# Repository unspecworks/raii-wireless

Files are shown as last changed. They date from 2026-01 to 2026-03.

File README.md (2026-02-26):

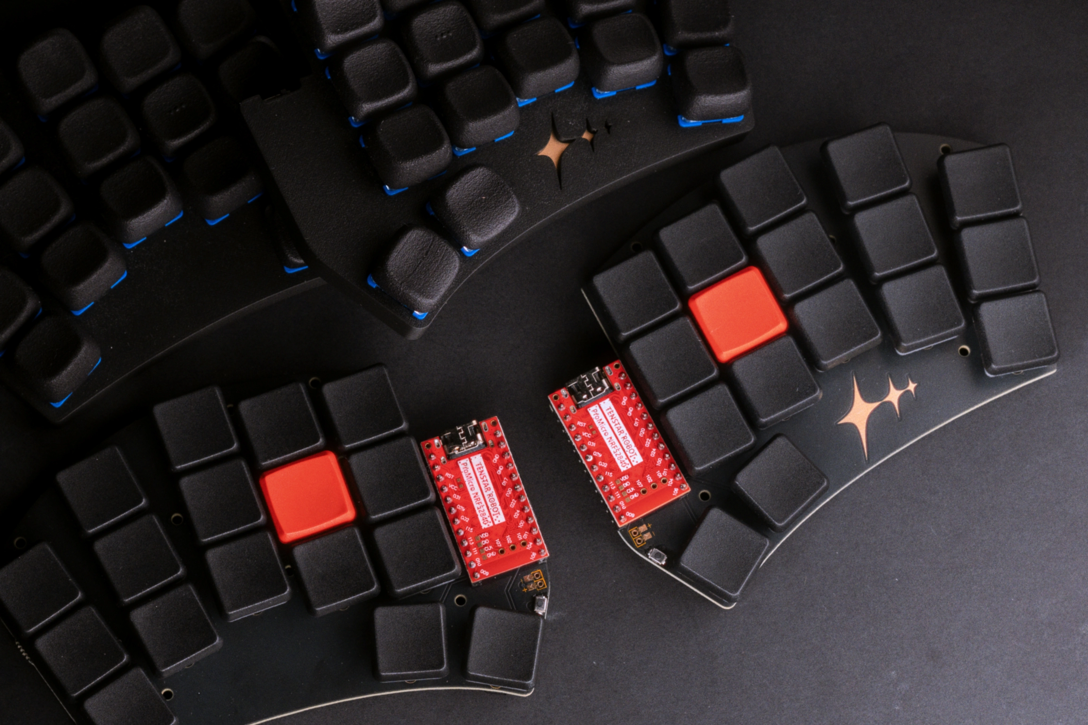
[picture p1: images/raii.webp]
RAII


# RAII Wireless

RAII-Wireless is a customized variant of [Sweep Bling LP](https://github.com/davidphilipbarr/Sweep), featuring splayed columns and various PCB and footprint updates.

## Modifications

* Applied splay to the ring and pinky columns
* Added support for Kailh Choc V2
* Compatible with Nice!Nano v2 or Pro Micro MCUs

## Project Structure

*   **[PCB](./pcb)**: KiCad design files.
*   **[Cases](./cases)**: 3D printable case files (STEP).
*   **[Images](./images)**: Gallery of the RAII Wireless keyboard.
*   **[Build Guide](./BUILD_GUIDES.md)**: Detailed assembly instructions and Bill of Materials.

### Firmware
* **ZMK Firmware**: You can use the Cradio firmware, which is the same as the Sweep's.

### Related
* **Wired Version**: [raii](https://github.com/unspecworks/raii) (Wired version with integrated RP2040)

## Sponsorship

This project is sponsored by [PCBWay](https://www.pcbway.com/).

> Note: PCBWay is a manufacturer of PCBs, and they sponsored this project by providing free PCBs. I really appreciate their support.

## License

[SOLDERPAD HARDWARE LICENSE VERSION 2.1](./LICENSE)

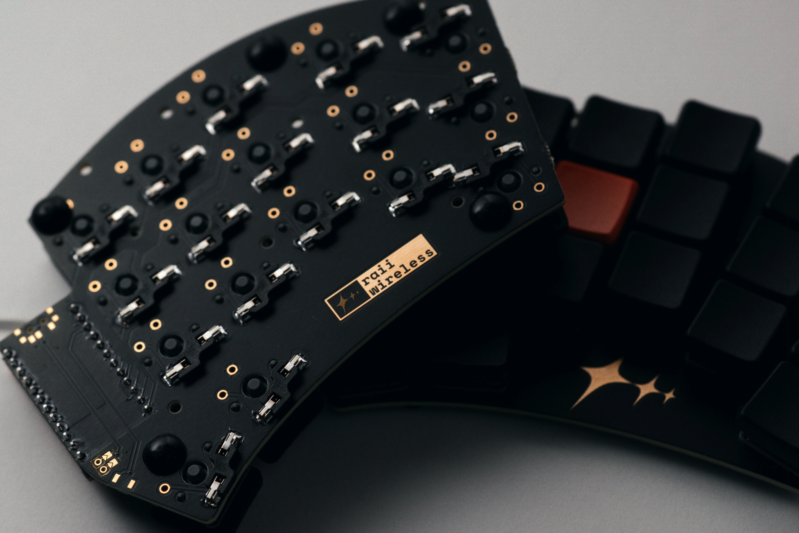
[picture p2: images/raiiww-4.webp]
RAII


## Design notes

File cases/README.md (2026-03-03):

# RAII Wireless Cases

This directory contains the 3D design files (STEP format) for the RAII Wireless keyboard cases.

## Overview

The RAII Wireless case is a two-part (Top and Bottom) case designed to house the PCB, battery, and switches securely.

## Case Files

Files are provided in STEP format, which is compatible with most 3D CAD software and slicers.

### Left Half
- `RAII_W_L_TOP.step`: Top plate/shell for the left side.
- `RAII_W_L_BOT.step`: Bottom shell for the left side.

### Right Half
- `RAII_W_R_TOP.step`: Top plate/shell for the right side.
- `RAII_W_R_TOP_LOGO.step`: Top plate/shell for the right side with logo on the top.
- `RAII_W_R_BOT.step`: Bottom shell for the right side.

## Hardware Requirements

To assemble the case, you will need:

- **Screws**: M2x6mm screws (8 total, 4 per side).
- **Feet**: Rubber feet or anti-slip pads for the bottom case.

## Design Features

- **Reset Mechanism**: The bottom case includes a built-in leaf spring mechanism to actuate the reset switch without needing to open the case.
- **Battery Compartment**: Designed to accommodate a 3.7V LiPo battery (recommended size: 351636 for case builds).
- **Slim Fit**: Optimized for a low-profile aesthetic that protects the MCU and battery while keeping the switches and keycaps exposed.

## Printing Recommendations

- **Material**: PLA, PETG
- **Orientation**: Print with the flat faces on the bed.
- **Supports**: May be required depending on your printer's bridging capabilities, especially for the screw holes and internal cavities.

> [!WARNING]
> This case is designed for FDM printing. Other methods, such as resin printing, may not be suitable for this design.

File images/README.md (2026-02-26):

# Gallery

This directory contains images of the RAII Wireless keyboard.

RAII
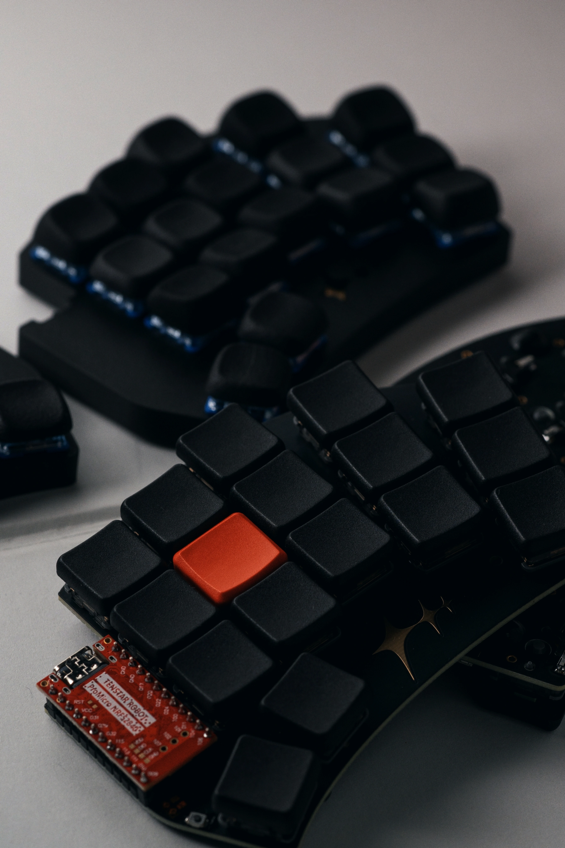
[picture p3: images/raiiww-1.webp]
RAII Wireless 1

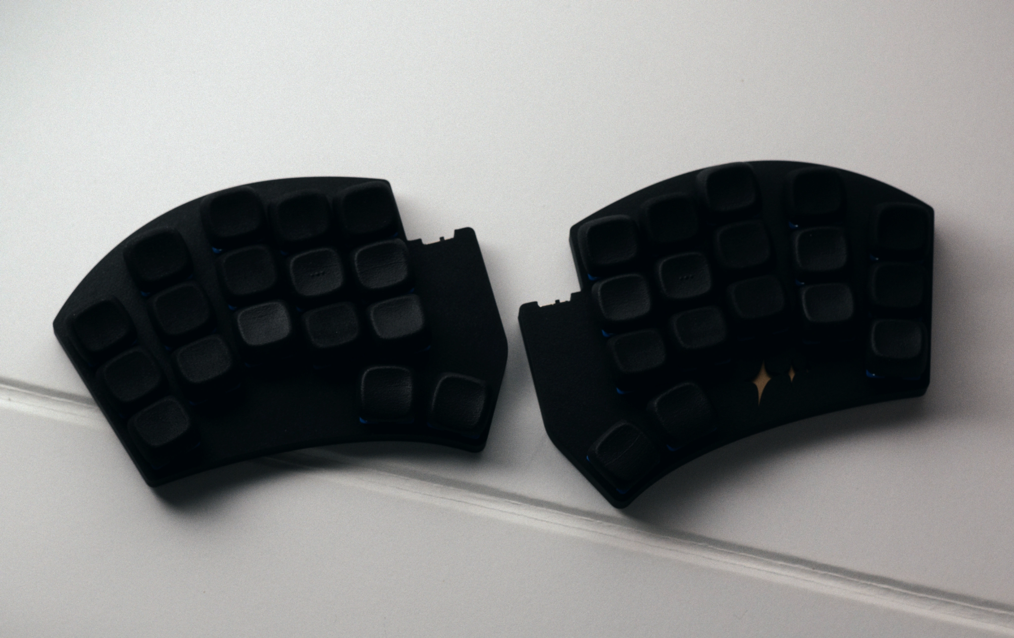
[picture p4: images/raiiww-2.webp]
RAII Wireless 2

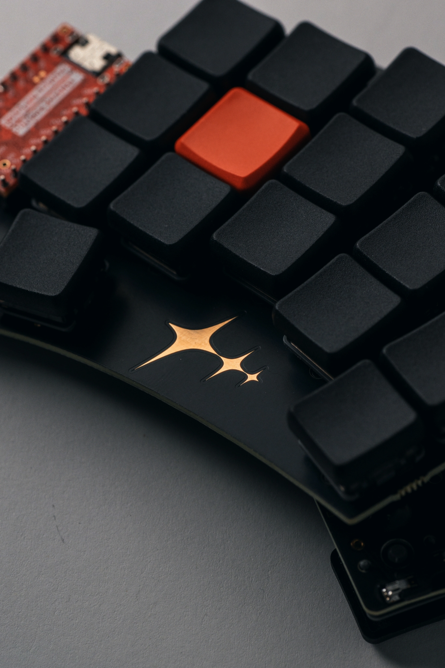
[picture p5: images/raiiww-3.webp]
RAII Wireless 3

RAII Wireless 4
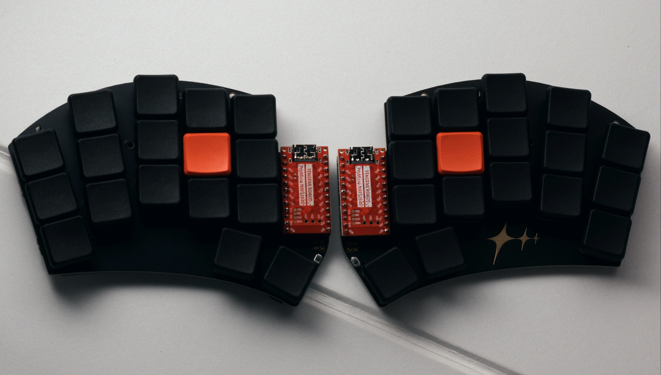
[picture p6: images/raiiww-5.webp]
RAII Wireless 5

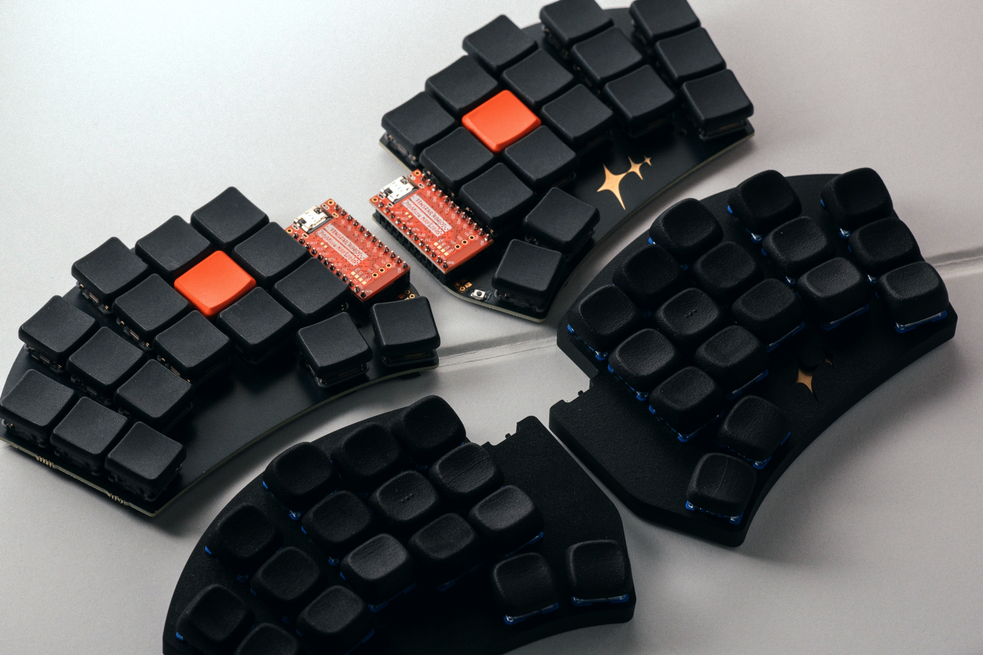
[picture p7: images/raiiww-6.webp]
RAII Wireless 6


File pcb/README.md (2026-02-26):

# RAII Wireless PCB

This directory contains the PCB design files for the RAII Wireless keyboard.

## Files

- `raii-wireless-rev1.kicad_pcb`: The main PCB design file (KiCad).

## Ordering Guide

To order these PCBs, you can upload the KiCad file or exported Gerbers to [PCBWay](https://www.pcbway.com/).

### Recommended Settings:
- **Material**: FR-4
- **Layer**: 2
- **Thickness**: 1.6mm
- **Surface Finish**: **ENIG** (Highly recommended) or HASL (Lead-free recommended)
- **Solder Mask**: **Matte Black Solder Mask**
- **Different designs in panel**: 2 (Left and Right halves)

> *Note: In my experience, PCBWay consistently delivers boards that meet exact technical specifications. Their range of customization options is significantly broader than those of many other services. For projects where the PCB is exposed, their **Matte Black Solder Mask** provides a particularly refined aesthetic. Considering the premium options available, the pricing is very reasonable and the production speed is impressive. I personally recommend the combination of **ENIG** and **Matte Black Solder Mask** for this build.*

## Building Tips

- **Battery Jumper**: Ensure you bridge the appropriate battery jumpers on the PCB before connecting your battery.
- **MCU Orientation**: Refer to the [Build Guide](../BUILD_GUIDES.md) for specific MCU orientation depending on whether you are using a case.

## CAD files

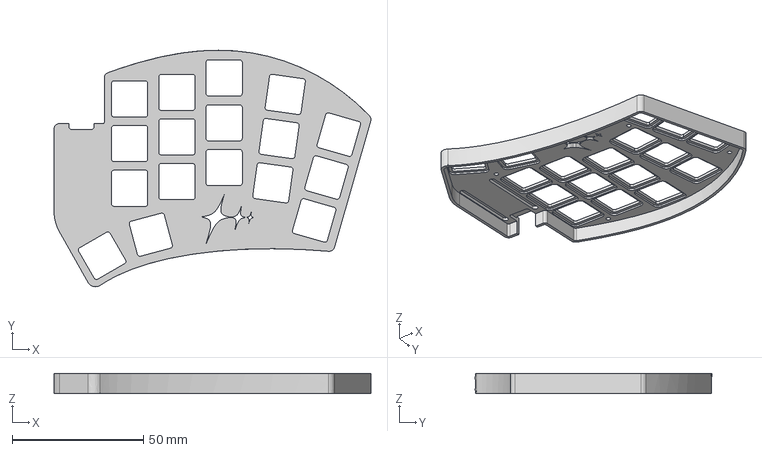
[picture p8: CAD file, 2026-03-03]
cases/RAII_W_R_TOP_LOGO.step
120.7 x 90.1 x 7.80 mm

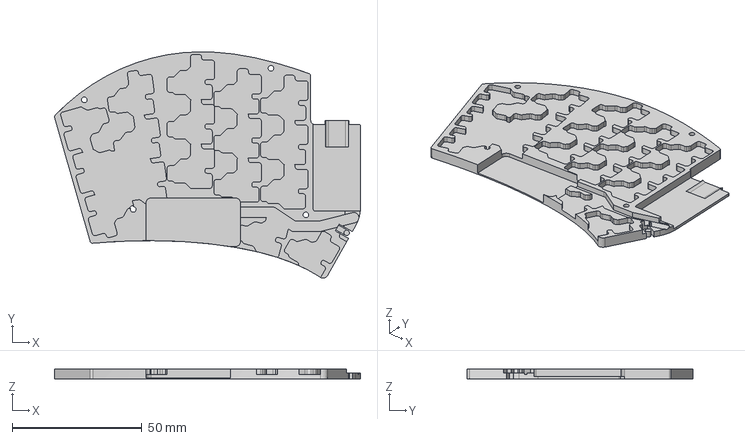
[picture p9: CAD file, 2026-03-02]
cases/RAII_W_L_BOT.step
117.8 x 87.1 x 4.00 mm

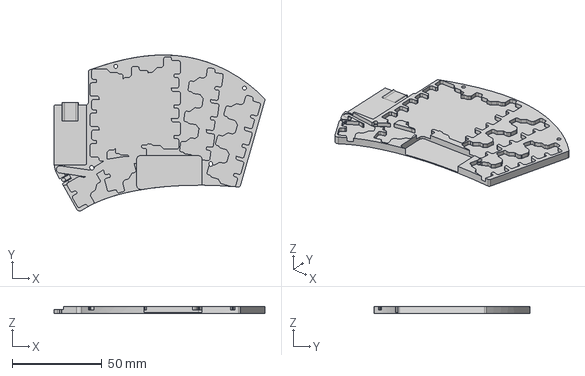
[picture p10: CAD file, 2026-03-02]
cases/RAII_W_R_BOT.step
117.8 x 87.1 x 4.00 mm

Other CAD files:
cases/RAII_W_L_TOP.step
cases/RAII_W_R_TOP.step

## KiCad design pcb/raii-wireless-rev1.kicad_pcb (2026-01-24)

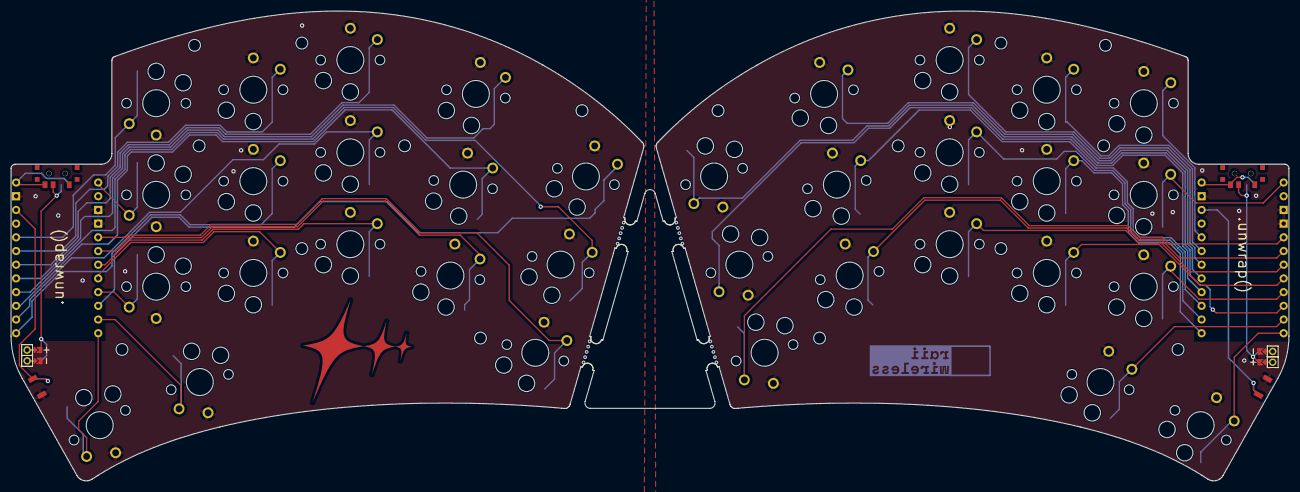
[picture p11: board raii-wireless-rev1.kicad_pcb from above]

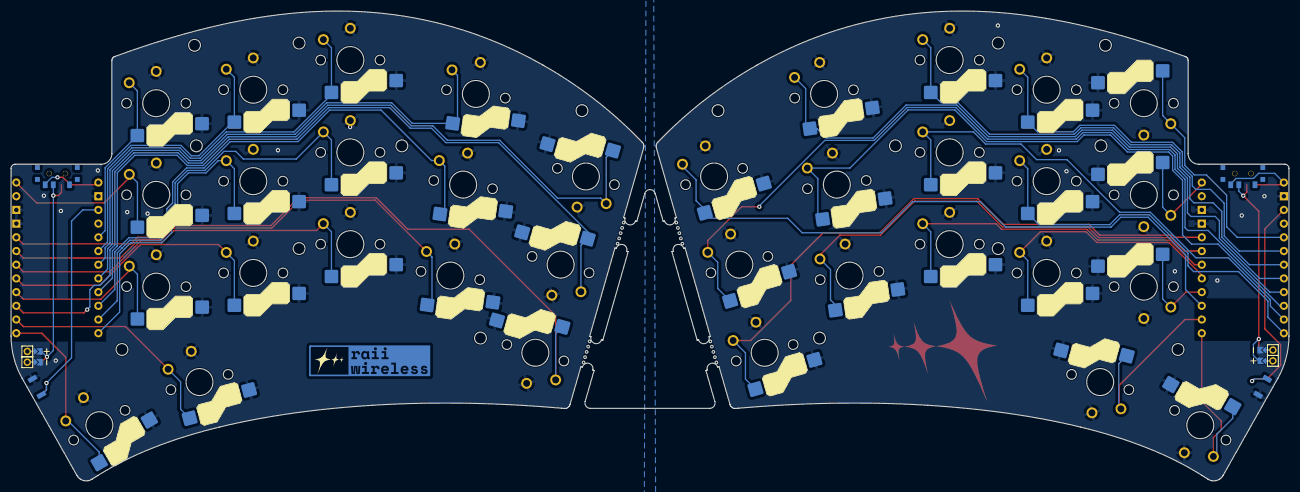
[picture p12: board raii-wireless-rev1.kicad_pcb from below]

Board: 2 copper layers, 236.9 x 87.1 mm, 60 parts (2 on the bottom side), 46 nets.

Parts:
Bat+1, Bat+1#2: MountingHole_Pad; 1pin_conn
BatGND1, BatGND1#2: MountingHole_Pad; 1pin_conn
JST1, JST1#2: Val**; jumper2p
REF_PUCK_R: Tenting Puck; Tenting_Puck2_no_pads
RSW1, RSW2: SW_Push_SMD; SW_SPST_B3U-1000P-DS
SW1, SW1_r1, SW2, SW2_r1, SW3, SW3_r1, SW4, SW4_r1, SW5, SW5_r1, SW6, SW6_r1, SW7, SW7_r1, SW8, SW8_r1, SW9, SW9_r1, SW10, SW10_r1, SW11, SW11_r1, SW12, SW12_r1, SW13, SW13_r1, SW14, SW14_r1, SW15, SW15_r1, SW16, SW16_r1, SW17, SW17_r1: SW_Push; SW_Hotswap_Kailh_Choc_V1_tweaked
SW_POWER1: SW_SPDT; SPDT_C128955
SW_POWERR1: SW_SPDT; SPDT_C128955
U1, U2: ProMicro-kbd; ProMicro_v3_min
e: Tenting Puck; Tenting_Puck2_no_pads
mouse-bite-2mm-slot2, mouse-bite-2mm-slot2#2, mouse-bite-2mm-slot2#3, mouse-bite-2mm-slot2#4: VAL**; mouse-bite-5mm-slot-with-space-for-track
x: MH; MountingHole_2.2mm_M2
x#2, x#3, x#4, x#5, x#6, x#7, x#8: MH; MountingHole_2.2mm_M2

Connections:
BAT_1: Bat+1#2.1, JST1#2.21, JST1#2.31
BAT_2: BatGND1#2.1, JST1#2.22, JST1#2.32
BT+: JST1#2.2, SW_POWER1.2 (B)
BT+_r: JST1.2, SW_POWERR1.2 (B)
R_BAT_1: Bat+1.1, JST1.22, JST1.32
R_BAT_2: BatGND1.1, JST1.21, JST1.31
Switch1: SW1.1, U1.10 (E6)
Switch1_r: SW1_r1.1, U2.10 (E6)
Switch2: SW2.1, U1.17 (F7)
Switch2_r: SW2_r1.1, U2.17 (F7)
Switch3: SW3.1, U1.18 (F6)
Switch3_r: SW3_r1.1, U2.18 (F6)
Switch4: SW4.1, U1.19 (F5)
Switch4_r: SW4_r1.1, U2.19 (F5)
Switch5: SW5.1, U1.20 (F4)
Switch5_r: SW5_r1.1, U2.20 (F4)
Switch6: SW6.1, U1.16 (B1)
Switch6_r: SW6_r1.1, U2.16 (B1)
Switch7: SW7.1, U1.15 (B3)
Switch7_r: SW7_r1.1, U2.15 (B3)
Switch8: SW8.1, U1.14 (B2)
Switch8_r: SW8_r1.1, U2.14 (B2)
Switch9: SW9.1, U1.13 (B6)
Switch9_r: SW9_r1.1, U2.13 (B6)
Switch10: SW10.1, U1.1 (TX)
Switch10_r: SW10_r1.1, U2.1 (TX)
Switch11: SW11.1, U1.5 (SDA)
Switch11_r: SW11_r1.1, U2.5 (SDA)
Switch12: SW12.1, U1.6 (SCL)
Switch12_r: SW12_r1.1, U2.6 (SCL)
Switch13: SW13.1, U1.7 (D4)
Switch13_r: SW13_r1.1, U2.7 (D4)
Switch14: SW14.1, U1.8 (C6)
Switch14_r: SW14_r1.1, U2.8 (C6)
Switch15: SW15.1, U1.9 (D7)
Switch15_r: SW15_r1.1, U2.9 (D7)
Switch16: SW16.1, U1.11 (B4)
Switch16_r: SW16_r1.1, U2.11 (B4)
Switch17: SW17.1, U1.12 (B5)
Switch17_r: SW17_r1.1, U2.12 (B5)
gnd: JST1#2.1, RSW1.1, SW1.2, SW2.2, SW3.2, SW4.2, SW5.2, SW6.2, SW7.2, SW8.2, SW9.2, SW10.2, SW11.2, SW12.2, SW13.2, SW14.2, SW15.2, SW16.2, SW17.2, U1.3 (GND), U1.4 (GND), U1.23 (GND)
gnd_r: JST1.1, RSW2.1, SW1_r1.2, SW2_r1.2, SW3_r1.2, SW4_r1.2, SW5_r1.2, SW6_r1.2, SW7_r1.2, SW8_r1.2, SW9_r1.2, SW10_r1.2, SW11_r1.2, SW12_r1.2, SW13_r1.2, SW14_r1.2, SW15_r1.2, SW16_r1.2, SW17_r1.2, U2.3 (GND), U2.4 (GND), U2.23 (GND)
raw: SW_POWER1.3 (C), U1.24 (RAW)
raw_r: SW_POWERR1.3 (C), U2.24 (RAW)
reset: RSW1.2, U1.22 (RST)
reset_r: RSW2.2, U2.22 (RST)

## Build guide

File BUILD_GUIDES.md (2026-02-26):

# Build Guide & Bill of Materials

## Bill of Materials (BOM)

| Item | Specification | Quantity | Notes |
| :--- | :--- | :--- | :--- |
| **Microcontroller** | Nice!Nano v2 | 2 | Pro Micro compatible |
| **Switches** | Kailh Choc v1 or v2 | 34 | |
| **Hotswap Sockets** | Kailh Choc Hotswap | 34 | |
| **Keycaps** | Choc Compatible | 34 | Ensure Choc spacing compatibility |
| **Reset Switch** | B3U-1000P | 2 | Tactile switch |
| **Power Switch** | MK-12C02 | 2 | Slide switch |
| **Battery** | 3.7V LiPo | 2 | 301230 (under MCU) or 351636 (with case) |
| **Screws** | M2x6mm | 8 | Required for case build |
| **Feet** | Rubber pads | - | Anti-slip |
| **Battery Connector**| PH2.0 (Optional) | 2 | Direct soldering recommended for cases |

---

## Assembly Instructions

Choose one of the two build configurations below based on whether you are using a case.

### Option A: With Case

raii-wireless-case

This method involves soldering the MCU directly to the PCB to achieve the slimmest possible profile.

1.  **MCU Installation**
    *   **Side**: Solder to the **bottom** (socket side).
    *   **Orientation**: Components must face **outwards**.
    *   **Safety**: Insulate the MCU underside (e.g., with Kapton tape) and trim all pins flush to prevent shorts.
2.  **Switches**
    *   **Power**: Install on the **top** (switch side).
    *   **Reset**: Install on the **bottom** (the case features a leaf spring to actuate this switch).
3.  **Battery**
    *   **Connection**: Direct soldering is recommended.
    *   **Jumpers**: Bridge the battery jumpers on the PCB before connecting.
4.  **Final Steps**
    *   Place the top case, install switches through the case, attach the bottom case, and secure with M2x6 screws.

---

### Option B: Without Case (Standard Build)

raii-wireless-case

A more traditional build using pin headers for the MCU.

1.  **MCU Installation**
    *   **Side**: Solder to the **top** (switch side) using pin headers.
    *   **Orientation**: Components face **inwards** (towards the PCB).
    *   **Tip**: Use sockets or tall headers if you plan to tuck the battery underneath.
2.  **Switches**
    *   **Power/Reset**: Can be installed on either side depending on preference.
3.  **Battery**
    *   **Connection**: Use PH2.0 connectors or direct solder.
    *   **Jumpers**: Bridge the battery jumpers on the PCB first.
4.  **Final Steps**
    *   Install switches into hotswap sockets and attach rubber feet directly to the PCB.

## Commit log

2026-01-31 doc: add build guides and case file.
    [RAII_W_L_BOT.step, RAII_W_L_TOP.step, RAII_W_R_BOT.step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]
2026-02-26 add comprehensive build guides with images and detailed component documentation for PCB and cases.
2026-03-02 case: updated reset button durability
    [RAII_W_L_BOT.step, RAII_W_R_BOT.step]
2026-03-03 case: Add top logo case model
    [RAII_W_R_TOP_LOGO.step]
